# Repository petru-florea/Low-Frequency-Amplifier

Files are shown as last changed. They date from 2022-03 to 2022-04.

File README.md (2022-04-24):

# Low Frequency Amplifier
### Revision 1.0
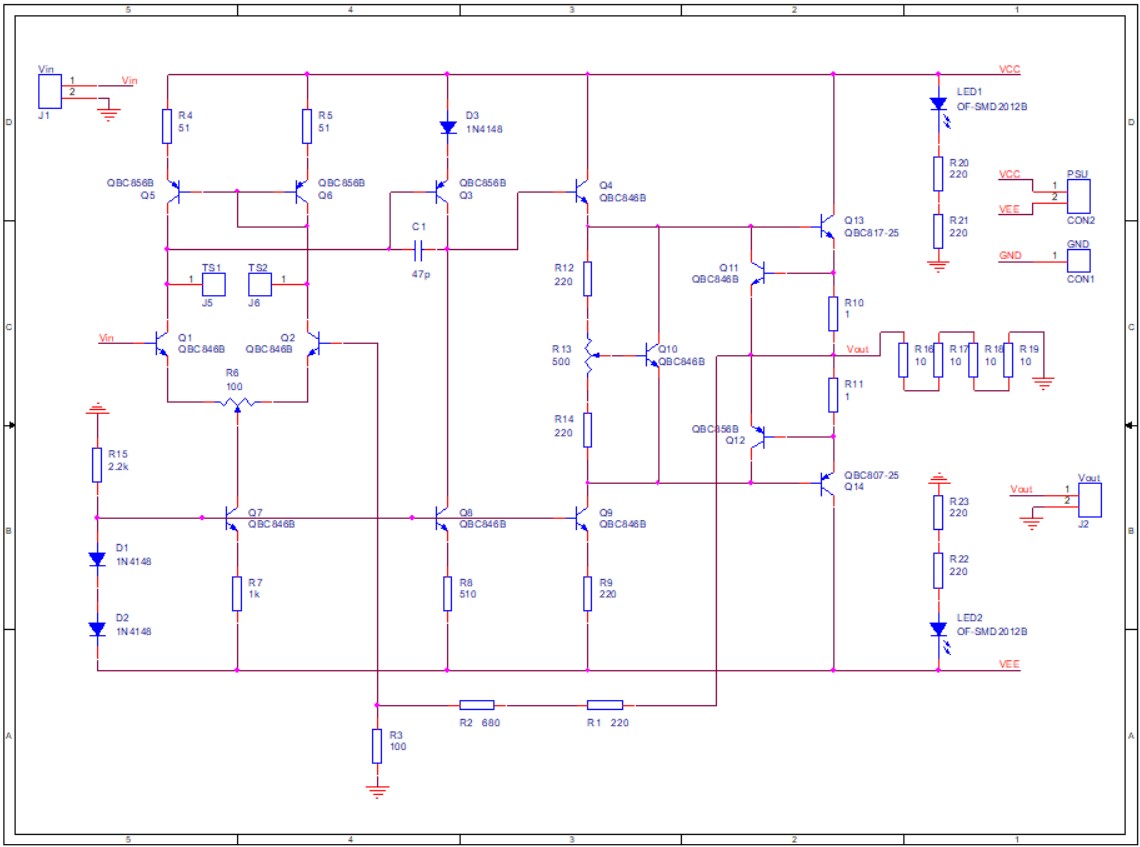
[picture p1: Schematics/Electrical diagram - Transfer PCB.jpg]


---
# README

### Quick summary

This is a BJT based Class AB low frquency amplifier (audio amplifier) PCB design using SMD technology.

This repository contains the OrCad design files, manufacturing Gerber/drill files, PDF/drawing files, and relevant documenation for this board.

### Design characteristics

+ VCC: 10V; VEE: -10V
+ Input signal, *ui* in the range: ±1 [V]
+ Output load, *RL*: 40 [Ω]
+ Input resistance *Ri* > 0.1 [MΩ]
+ Output resistance *Ro* < 0.8 [Ω]
+ Voltage gain, *Av*: 10
+ Operating temperature range: -20 - 120°C
+ The presence of supply voltages is signaled by two LEDs

### Project folder structure

Starting from the top level:
+ *Bill_of_Materials*  - This contains the bill of materials in .xls and .BOM formats
+ *Data sheets* - This contains the data sheets for the electronic devices used
+ *Layout* - This contains the PCB Gerbers and drill file for manufacture, there is also a .jpg image with the PCB layout
+ *Project docs* - This contains the relevant documenation for this project (in Romanian)
+ *Schematics* - This contains the original OrCad schematic and design files. There are two folders inside: 
    - *Simulation* - contains the OrCad schematic used for circuit simulation
    - *Transfer PCB* - contains the OrCad schematic used for exporting the circuit to the OrCad PCB Editor
+ *Simulations* - This folder contains images of different simulations that prove the circuit is working adequately

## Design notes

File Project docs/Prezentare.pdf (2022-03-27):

## UNIVERSITATEA POLITEHNICA din BUCURESTI

Facultatea de Electronică, Telecomunicații și Tehnologia Informației

### Referat

### Proiect 1 - Dispozitive și circuite electronice

### Tema:

Amplificator de tensiune (joasă frecvență)

Florea Petru
Grupa: 432E

Bucuresti 2021

Date initiale de proiectare: N = 8

Să se proiecteze și realizeze un amplificator de tensiune (joasă frecvență) având următoarele caracteristici:
- Semnal de intrare, ui in gama: 400 [mV];
- Sarcina la ieșire, RL: 40 [Ω];
- Rezistența de intrare Ri > 0,1 [MΩ];
- Rezistența de ieșire Ro < 0,8 [Ω];
- Amplificare în tensiune, Av: 10;
- Domeniul temperaturilor de funcționare: 0-70ºC (verificabil prin testare în temperatură);
- Semnalizarea prezenței tensiunilor de alimentare cu diodă de tip LED.

Introducere:
Amplificatorul de tensiune este un circuit care are rolul de a furniza la iesirea sa o tensiune proportionala cu cea de la intrare. Relatia de baza este:

Uies=AV⋅Uin (1)

unde:
- Uies= este tensiunea de la iesirea amplificatorului
- Uin= este tensiunea de la intrarea amplificatorului
- Av= amplificarea amplificatorului (marime adimensionala) mai mare, in modul decat 1. Daca Av>0, atunci amplificatorul se numeste neinversor, iar daca Av<0, amplificatorul se numeste inversor.

Formula (1) este mai greu de indeplinit cu exactitate in practica, deoarece marimea Av nu este constanta, si depinde de mai multi factori, printre care si Uin, ceea ce face ca amplificatoarele de precizie sa fie realizare cu reactie negativa puternica. Pentru aceasta, se realizeaza un amplificator cu doua intrari: una inversoare, si cealalta neinversoare (amplificator diferential). Amplificatorul amplifica de fapt diferenta tensiunilor de la intrarea neinversoare, respectiv inversoare.

La intrarea neinversoare se aplica semnalul, iar la cea inversoare o fractiune din tensiunea de la iesirea amplificatorului, f⋅Uies cu f<1.

Daca amplificarea in bucla deschisa av (calculata in lipsa reactiei negative – intrarea inversoare conectcata la masa) indeplineste relatia:
aV

⋅f >>1

se poate demonstra ca amplificarea in prezenta reactiei negative AV≅1/f, deci constanta.

Schema bloc a amplificatorului de tensiune:

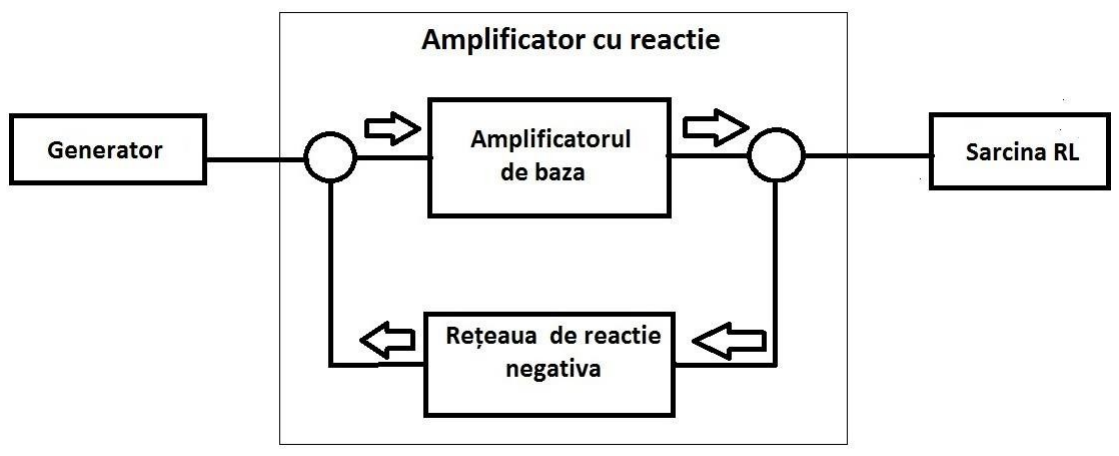
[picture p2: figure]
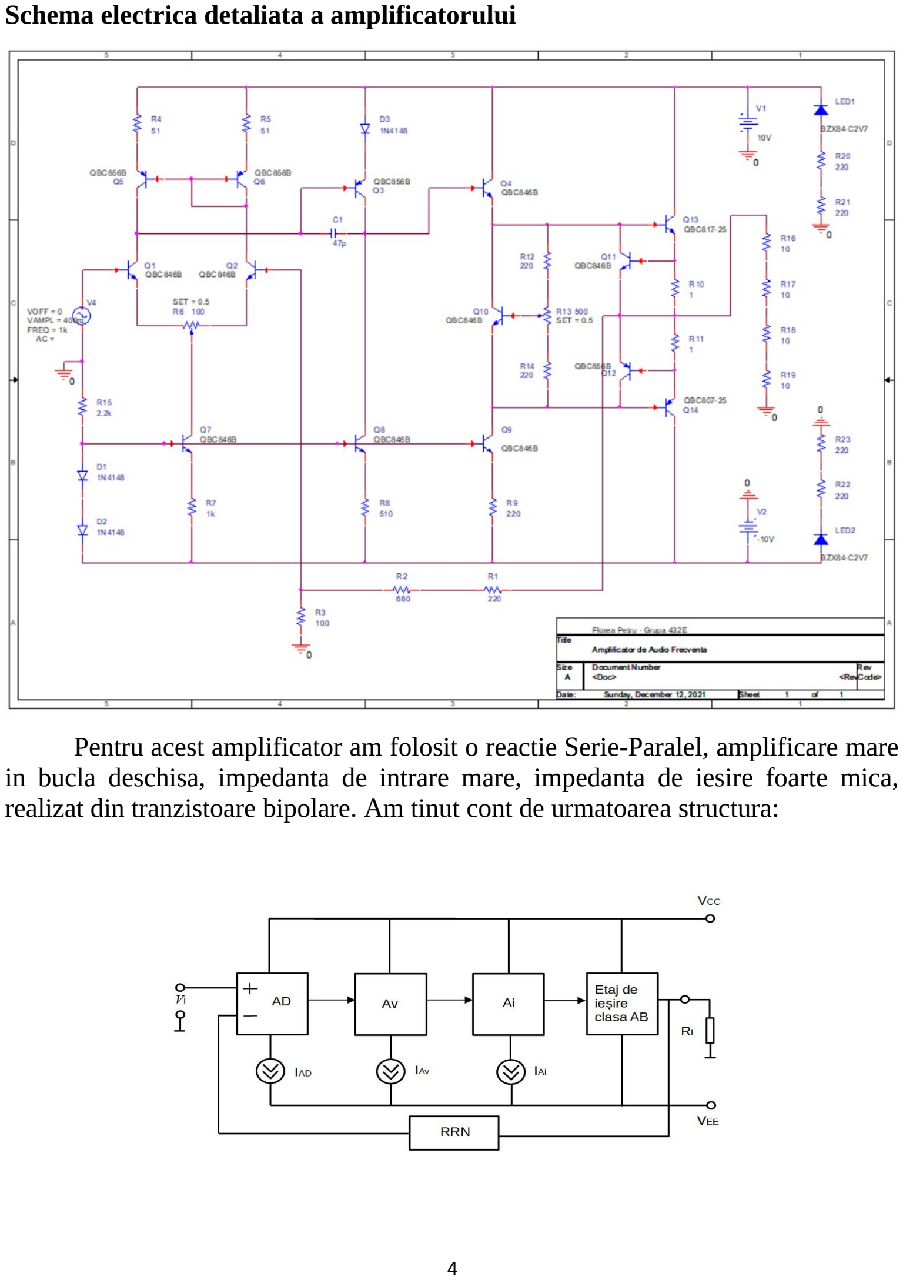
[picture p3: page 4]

Schema electrica detaliata a amplificatorului

Pentru acest amplificator am folosit o reactie Serie-Paralel, amplificare mare in bucla deschisa, impedanta de intrare mare, impedanta de iesire foarte mica, realizat din tranzistoare bipolare. Am tinut cont de urmatoarea structura:

Circuitul de intrare Q1 si Q2 este un amplificator diferential cu tranzistoare bipolare de joasa frecventa si mica putere. Curentul prin cele 2 tranzistoare este dat de sursa de curent Q7. Curentul prin acest tranzistor este dat de relatia:
I = (2VD-VBE)/R7 = 0,6 mA. Acest tranzistor alimenteaza cele 2 tranzistoare din diferential cu un curent simetric de aproximativ 0,3 mA.
Etajul diferential continua cu o oglinda de curent simetrica. Tranzistoarele Q5 si Q6 sunt tranzistoare de putere mica (65V, 100mA, β=290) ce au cate o rezistenta de 51Ω in emitor. Rolul acestei oglinzi de curent este sa forteze acelasi curent la iesirea din oglinda, pentru a avea liniaritate cat mai buna si distorsiuni cat mai mici.
Etajul diferential este urmat de amplificatorul in tensiune Q3, care este un tranzistor PNP de mica putere (65V, 100mA, β=290). Condensatorul conectat intre baza si colectorul tranzistorului Q3 este un condensator de compensare (efectul Miller), acesta are rolul de a modifica banda de frecventa. Alimentarea etajului este asigurata de tranzistorul Q8. Curentul prin acest tranzistor este dat de relatia: I = (2VD-VBE)/R8 = 1,1 mA
Etajul final este in clasa AB, fiind compus din 2 tranzistoare de putere medie Q13, Q14 (45V, 800mA, β =160). Etajul AB asigura o amplificare in putere cu un randament bun la un nivel de distorsiuni redus. De asemenea, a fost indrodusa protectia la suprasarcina sau scurtcircuit. Aceasta protectie este realizata cu grupul Q11, R10 pentru tranzistorul Q13 si grupul Q12, R11 pentru tranzistorul Q14. Diodele LED lucreaza in conductie, datorata rezistentei de 440Ω in serie. Diodele cu jonctiune p-n lucreaza in conductie: diodele D1 si D2 avand un curent de aproximativ 4 mA, iar D3 de aproximativ 1,1 mA.
Reteaua de reactie negative este alcatuita din tranzistorul Q2, respectiv rezistentele R1, R2 si R3. Amplificare in bucla inchisa a montajului este data de formula A=(R1+R2+R3)/R3. Pentru a respecta cerintele de proiectare, am ales raportul rezistentelor sa fie aproximativ 9.

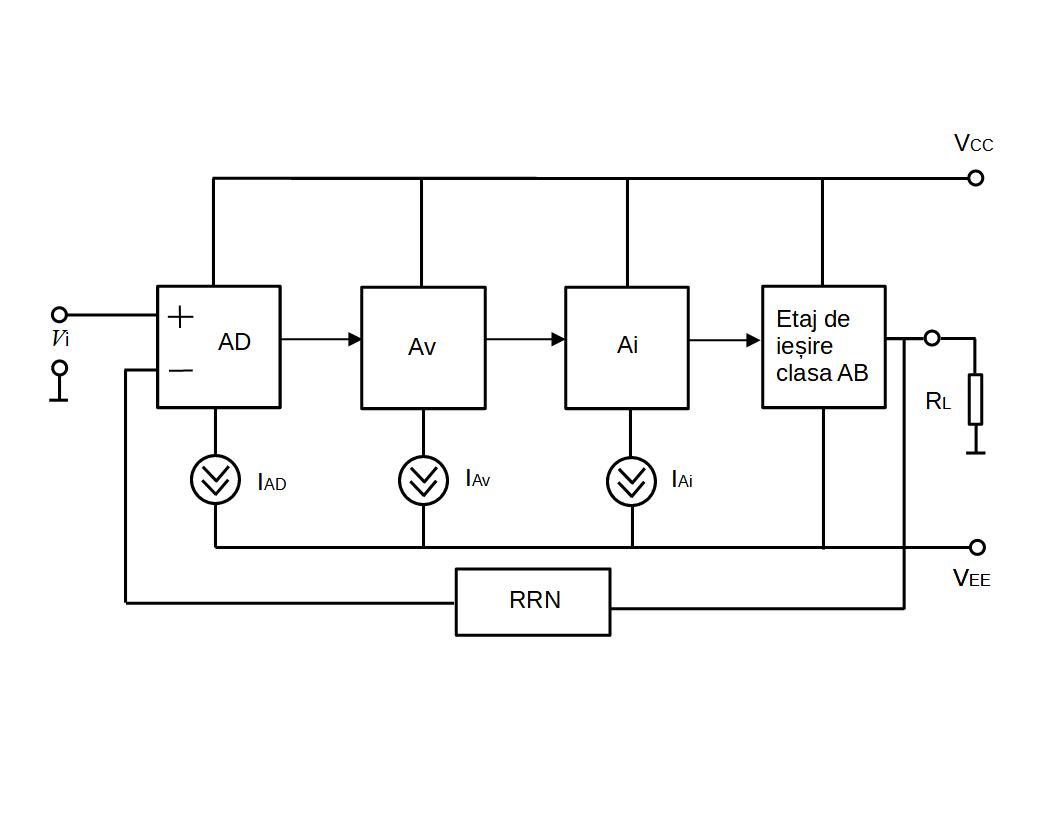
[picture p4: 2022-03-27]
Block schematic.jpg

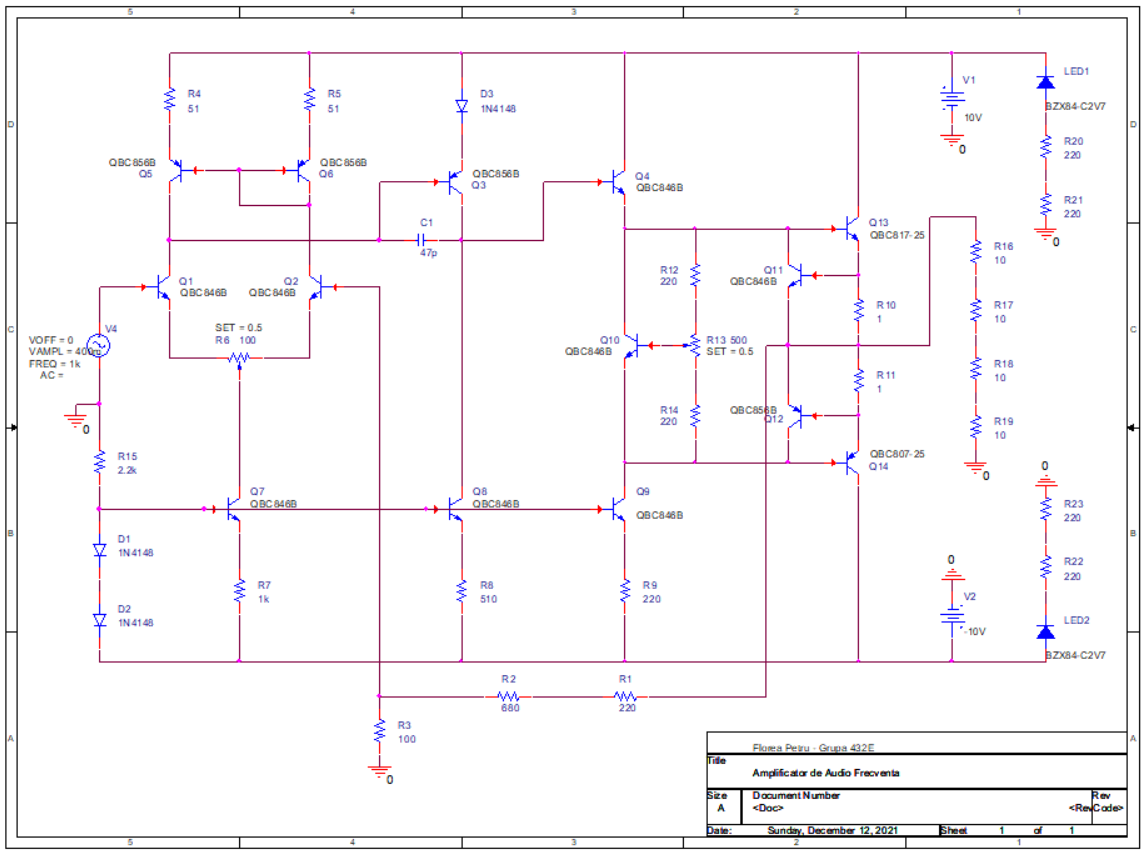
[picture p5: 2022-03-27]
Schematics/Electrical diagram - Simulation.PNG

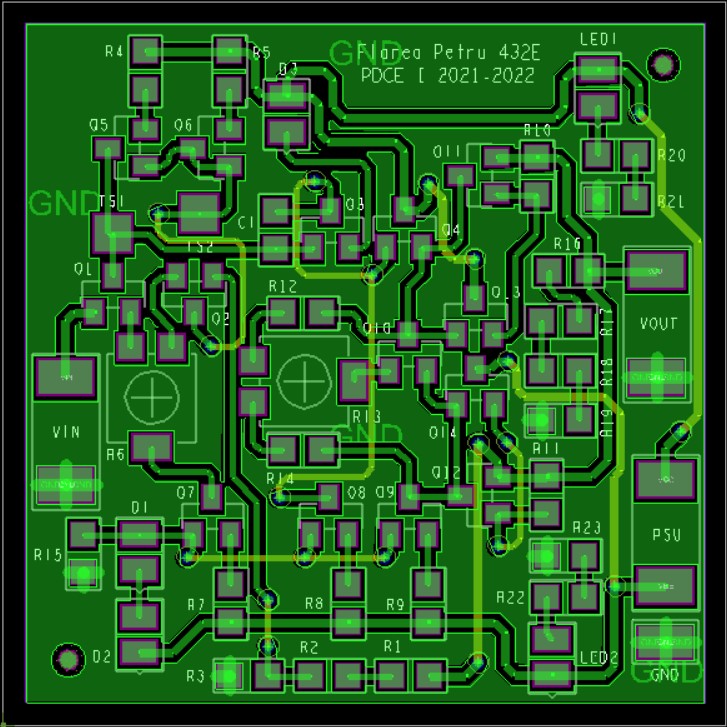
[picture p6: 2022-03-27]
Layout/Layout.jpg

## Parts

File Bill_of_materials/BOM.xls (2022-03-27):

Anexa a1 - Grupa 432E - Tema 2 - Amplificator de tensiune (joasă frecvență)
Nr. Crt. | Nume | Catalog | Cod distrib | Nume prod | Prod | Clasă | Qty fix | Qty final | Qty min | Descriere | Distribuitor | Pret (fara TVA) referinta/buc. TME România | Pret total pe reper (fara TVA) - propus
1 | 0 ohm | (LINK) (http://www.tme.eu/ro/details/smd1206-0r/rezistente-smd-1206/royal-ohm/1206s4j0000t5e/) | 1206S4J0000T5E | 1206S4J0000T5E | SR PASSIVES | rezistor | 0 |  | 0 | Rezistor: thick film; SMD; 1206; 0Ω; 0,25W; ±5%; -55÷125°C | TME România | 0.03841 | 0
2 | 0.47 | (LINK) (http://www.tme.eu/ro/details/smd0805-0r47/rezistente-smd-0805/royal-ohm/0805s8j047kt5e/) | SMD0805-0R47 | 0805S8J047KT5E | ROYAL OHM | rezistor | 30 |  | 0 | Rezistor SMD, chip, 0805, 0.47Ω, ±5%, 0.125W | TME România | 0.01454 | 0.4362
3 | 1 | (LINK) (https://www.tme.eu/ro/details/smd0805-1r/rezistente-smd-0805/royal-ohm/0805s8j010jt5e/) | SMD0805-1R-5% | 0805S8J010JT5E | ROYAL OHM | rezistor | 30 |  | 2 | Rezistor SMD, chip, 0805, 1Ω, ±5%, 0.125W | TME România | 0.01723 | 0.5169
4 | 4.7 | (LINK) (https://www.tme.eu/ro/details/smd0805-4r7/rezistente-smd-0805/royal-ohm/0805s8j047jt5e/) | SMD0805-4R7-5% | 0805S8J047JT5E | ROYAL OHM | rezistor | 10 |  | 0 | Rezistor SMD, chip, 0805, 4.7Ω, ±5%, 0.125W | TME România | 0.01723 | 0.1723
5 | 10 | (LINK) (https://www.tme.eu/ro/details/smd0805-10r/rezistente-smd-0805/royal-ohm/0805s8j0100t5e/) | SMD0805-10R-5% | 0805S8J0100T5E | ROYAL OHM | rezistor | 10 |  | 4 | Rezistor SMD, chip, 0805, 10Ω, ±5%, 0.125W | TME România | 0.01723 | 0.1723
6 | 22 | (LINK) (https://www.tme.eu/ro/details/smd0805-22r-1%25/rezistente-smd-0805/royal-ohm/0805s8f220jt5e/) | SMD0805-22R-1% | 0805S8F220JT5E | ROYAL OHM | rezistor | 20 |  | 0 | Rezistor SMD, chip, 0805, 22Ω, ±1%, 0.125W | TME România | 0.02127 | 0.4254
7 | 33 | (LINK) (https://www.tme.eu/ro/details/smd0805-33r/rezistente-smd-0805/royal-ohm/0805s8j0330t5e/) | SMD0805-33R-5% | 0805S8J0330T5E | ROYAL OHM | rezistor | 20 |  | 0 | Rezistor SMD, chip, 0805, 33Ω, ±5%, 0.125W | TME România | 0.01723 | 0.3446
8 | 51 | (LINK) (http://www.tme.eu/ro/details/rc0805jr-0751r/rezistente-smd-0805/yageo/rc0805jr-0751rl/) | SMD0805-51R-5% | 0805S8J0510T5E | ROYAL OHM | rezistor | 40 |  | 2 | Rezistor SMD, chip, 0805, 51Ω, ±5%, 0.125W | TME România | 0.0261 | 1.044
9 | 68 | (LINK) (http://www.tme.eu/ro/details/smd0805-68r-1%25/rezistente-smd-0805/royal-ohm/0805s8f680jt5e/) | SMD0805-68R-1% | 0805S8F680JT5E | ROYAL OHM | rezistor | 10 |  | 0 | Rezistor SMD, chip, 0805, 68Ω, ±1%, 0.125W | TME România | 0.04662 | 0.4662
10 | 82 | (LINK) (https://www.tme.eu/ro/details/wf08p-82r-5%25/rezistente-smd-0805/walsin/wf08p820jtl/) | SMD0805-82R-5% | WF08P820JTL | WALSIN | rezistor | 20 |  | 0 | Rezistor SMD, chip, 0805, 82Ω, ±5%, 0.125W | TME România | 0.0172 | 0.344
11 | 100 | (LINK) (https://www.tme.eu/ro/details/smd0805-100r/rezistente-smd-0805/royal-ohm/0805s8j0101t5e/) | SMD0805-100R-5% | 0805S8J0101T5E | ROYAL OHM | rezistor | 60 |  | 1 | Rezistor SMD, chip, 0805, 100Ω, ±5%, 0.125W | TME România | 0.01723 | 1.0338
12 | 150 | (LINK) (https://www.tme.eu/ro/details/smd0805-150r/rezistente-smd-0805/royal-ohm/0805s8j0151t5e/) | SMD0805-150R-5% | 0805S8F1500T5E | ROYAL OHM | rezistor | 20 |  | 0 | Rezistor SMD, chip, 0805, 150Ω, ±5%, 0.125W | TME România | 0.01723 | 0.3446
13 | 220 | (LINK) (http://www.tme.eu/ro/details/smd0805-220r-1%25/rezistente-smd-0805/royal-ohm/0805s8f2200t5e/) | SMD0805-220R-5% | 0805S8J0221T5E | ROYAL OHM | rezistor | 20 |  | 8 | Rezistor SMD, chip, 0805, 220Ω, ±5%, 0.125W | TME România | 0.02127 | 0.4254
14 | 330 | (LINK) (https://www.tme.eu/ro/details/smd0805-330r/rezistente-smd-0805/royal-ohm/0805s8j0331t5e/) | SMD0805-330R-5% | 0805S8J0331T5E | ROYAL OHM | rezistor | 20 |  | 0 | Rezistor SMD, chip, 0805, 330Ω, ±5%, 0.125W | TME România | 0.01723 | 0.3446
15 | 470 | (LINK) (https://www.tme.eu/ro/details/smd0805-470r/rezistente-smd-0805/royal-ohm/0805s8j0471t5e/) | SMD0805-470R-5% | 0805S8J0471T5E | ROYAL OHM | rezistor | 20 |  | 0 | Rezistor SMD, chip, 0805, 470Ω, ±5%, 0.125W | TME România | 0.01723 | 0.3446
16 | 510 | (LINK) (https://www.tme.eu/ro/details/smd0805-510r/rezistente-smd-0805/royal-ohm/0805s8j0511t5e/) | SMD0805-510R-5% | 0805S8J0511T5E | YAGEO | rezistor | 30 |  | 1 | Rezistor SMD, chip, 0805, 510Ω, ±5%, 0.125W | TME România | 0.01723 | 0.5169
17 | 680 | (LINK) (https://www.tme.eu/ro/details/smd0805-680r/rezistente-smd-0805/royal-ohm/0805s8j0681t5e/) | SMD0805-680R-5% | 0805S8J0681T5E | ROYAL OHM | rezistor | 30 |  | 1 | Rezistor SMD, chip, 0805, 680Ω, ±5%, 0.125W | TME România | 0.01723 | 0.5169
18 | 820 | (LINK) (https://www.tme.eu/ro/details/smd0805-820r/rezistente-smd-0805/royal-ohm/0805s8j0821t5e/) | SMD0805-820R-5% | 0805S8J0821T5E | ROYAL OHM | rezistor | 20 |  | 0 | Rezistor SMD, chip, 0805, 820Ω, ±5%, 0.125W | TME România | 0.01723 | 0.3446
19 | 910 | (LINK) (https://www.tme.eu/ro/details/rc0805jr-07910r/rezistente-smd-0805/yageo/rc0805jr-07910rl/) | SMD0805-910R-5% | RC0805JR-07910RL | YAGEO | rezistor | 20 |  | 0 | Rezistor SMD, chip, 0805, 910Ω, ±5%, 0.125W | TME România | 0.0261 | 0.522
20 | 1k | (LINK) (https://www.tme.eu/ro/details/smd0805-1k/rezistente-smd-0805/royal-ohm/0805s8j0102t5e/) | SMD0805-1K-5% | 0805S8J0102T5E | ROYAL OHM | rezistor | 100 |  | 1 | Rezistor SMD, chip, 0805, 1kΩ, ±5%, 0.125W | TME România | 0.01723 | 1.723
21 | 1.5k | (LINK) (https://www.tme.eu/ro/details/wf08p-1k5-5%25/rezistente-smd-0805/walsin/wf08p152jtl/) | SMD0805-1K5-5% | WF08P152JTL | WALSIN | rezistor | 20 |  | 0 | Rezistor SMD, chip, 0805, 1.5kΩ, ±5%, 0.125W | TME România | 0.0172 | 0.344
22 | 1.8k | (LINK) (https://www.tme.eu/ro/details/smd0805-1k8/rezistente-smd-0805/royal-ohm/0805s8j0182t5e/) | SMD0805-1K8-5% | 0805S8J0182T5E | ROYAL OHM | rezistor | 20 |  | 0 | Rezistor SMD, chip, 0805, 1.8kΩ, ±5%, 0.125W | TME România | 0.01723 | 0.3446
23 | 2k | (LINK) (https://www.tme.eu/ro/details/smd0805-2k/rezistente-smd-0805/royal-ohm/0805s8j0202t5e/) | SMD0805-2K-5% | 0805S8J0202T5E | ROYAL OHM | rezistor | 80 |  | 0 | Rezistor SMD, chip, 0805, 2kΩ, ±5%, 0.125W | TME România | 0.01723 | 1.3784
24 | 2.2k | (LINK) (https://www.tme.eu/ro/details/smd0805-2k2/rezistente-smd-0805/royal-ohm/0805s8j0222t5e/) | SMD0805-2K2-5% | 0805S8J0222T5E | ROYAL OHM | rezistor | 20 |  | 1 | Rezistor SMD, chip, 0805, 2.2kΩ, ±5%, 0.125W | TME România | 0.01723 | 0.3446
25 | 2.7k | (LINK) (https://www.tme.eu/ro/details/smd0805-2k7/rezistente-smd-0805/royal-ohm/0805s8j0272t5e/) | SMD0805-2K7-5% | 0805S8F2701T5E | ROYAL OHM | rezistor | 20 |  | 0 | Rezistor SMD, chip, 0805, 2.7kΩ, ±5%, 0.125W | TME România | 0.01723 | 0.3446
26 | 3.3k | (LINK) (https://www.tme.eu/ro/details/smd0805-3k3/rezistente-smd-0805/royal-ohm/0805s8j0332t5e/) | SMD0805-3K3-5% | 0805S8J0332T5E | ROYAL OHM | rezistor | 30 |  | 0 | Rezistor SMD, chip, 0805, 3.3kΩ, ±5%, 0.125W | TME România | 0.01723 | 0.5169
27 | 3.9k | (LINK) (https://www.tme.eu/ro/details/smd0805-3k9/rezistente-smd-0805/royal-ohm/0805s8j0392t5e/) | SMD0805-3K9-5% | 0805S8J0392T5E | ROYAL OHM | rezistor | 20 |  | 0 | Rezistor SMD, chip, 0805, 3.9kΩ, ±5%, 0.125W | TME România | 0.01723 | 0.3446
28 | 4.7k | (LINK) (https://www.tme.eu/ro/details/smd0805-4k7/rezistente-smd-0805/royal-ohm/0805s8j0472t5e/) | SMD0805-4K7-5% | 0805S8J0472T5E | ROYAL OHM | rezistor | 30 |  | 0 | Rezistor SMD, chip, 0805, 4.7kΩ, ±5%, 0.125W | TME România | 0.01723 | 0.5169
29 | 5.6k | (LINK) (https://www.tme.eu/ro/details/smd0805-5k6/rezistente-smd-0805/royal-ohm/0805s8j0562t5e/) | SMD0805-5K6-5% | 0805S8J0562T5E | ROYAL OHM | rezistor | 40 |  | 0 | Rezistor SMD, chip, 0805, 5.6kΩ, ±5%, 0.125W | TME România | 0.01723 | 0.6892
30 | 6.8k | (LINK) (https://www.tme.eu/ro/details/rc0805jr-076k8/rezistente-smd-0805/yageo/rc0805jr-076k8l/) | SMD0805-6K8-5% | RC0805JR-076K8L | YAGEO | rezistor | 20 |  | 0 | Rezistor SMD, chip, 0805, 6.8kΩ, ±5%, 0.125W | TME România | 0.0261 | 0.522
31 | 8.2k | (LINK) (https://www.tme.eu/ro/details/smd0805-8k2/rezistente-smd-0805/royal-ohm/0805s8j0822t5e/) | SMD0805-8K2-5% | 0805S8J0822T5E | ROYAL OHM | rezistor | 30 |  | 0 | Rezistor SMD, chip, 0805, 8.2kΩ, ±5%, 0.125W | TME România | 0.01723 | 0.5169
32 | 9.1k | (LINK) (https://www.tme.eu/ro/details/smd0805-9k1/rezistente-smd-0805/royal-ohm/0805s8j0912t5e/) | SMD0805-9K1-5% | 0805S8J0912T5E | ROYAL OHM | rezistor | 20 |  | 0 | Rezistor SMD, chip, 0805, 9.1kΩ, ±5%, 0.125W | TME România | 0.01723 | 0.3446
33 | 10k | (LINK) (https://www.tme.eu/ro/details/smd0805-10k/rezistente-smd-0805/royal-ohm/0805s8j0103t5e/) | SMD0805-10K-5% | 0805S8J0103T5E | ROYAL OHM | rezistor | 100 |  | 0 | Rezistor SMD, chip, 0805, 10kΩ, ±5%, 0.125W | TME România | 0.01723 | 1.723
34 | 15k | (LINK) (https://www.tme.eu/ro/details/smd0805-15k/rezistente-smd-0805/royal-ohm/0805s8j0153t5e/) | SMD0805-15K-5% | 0805S8J0153T5E | ROYAL OHM | rezistor | 30 |  | 0 | Rezistor SMD, chip, 0805, 15kΩ, ±5%, 0.125W | TME România | 0.01723 | 0.5169
35 | 22k | (LINK) (https://www.tme.eu/ro/details/smd0805-22k/rezistente-smd-0805/royal-ohm/0805s8j0223t5e/) | SMD0805-22K-5% | 0805S8J0223T5E | ROYAL OHM | rezistor | 30 |  | 0 | Rezistor SMD, chip, 0805, 22kΩ, ±5%, 0.125W | TME România | 0.01723 | 0.5169
36 | 47k | (LINK) (http://www.tme.eu/ro/details/smd0805-47k/rezistente-smd-0805/royal-ohm/0805s8j0473t5e/) | SMD0805-47K-5% | 0805S8J0473T5E | ROYAL OHM | rezistor | 40 |  | 0 | Rezistor: thick film; SMD; 0805; 47kΩ; 0,125W; ±5%; -55÷125°C | TME România | 0.01723 | 0.6892
37 | 68k | (LINK) (https://www.tme.eu/ro/details/smd0805-68k/rezistente-smd-0805/royal-ohm/0805s8j0683t5e/) | SMD0805-68K-5% | 0805S8J0683T5E | ROYAL OHM | rezistor | 20 |  | 0 | Rezistor SMD, chip, 0805, 68kΩ, ±5%, 0.125W | TME România | 0.01723 | 0.3446
38 | 100k | (LINK) (https://www.tme.eu/ro/details/smd0805-100k/rezistente-smd-0805/royal-ohm/0805s8j0104t5e/) | SMD0805-100K-5% | 0805S8J0104T5E | ROYAL OHM | rezistor | 100 |  | 0 | Rezistor SMD, chip, 0805, 100kΩ, ±5%, 0.125W | TME România | 0.01723 | 1.723
39 | 150k | (LINK) (http://www.tme.eu/ro/details/smd0805-150k/rezistente-smd-0805/royal-ohm/0805s8j0154t5e/) | SMD0805-150K-5% | 0805S8J0154T5E | ROYAL OHM | rezistor | 30 |  | 0 | Rezistor SMD, chip, 0805, 150kΩ, ±5%, 0.125W | TME România | 0.01723 | 0.5169
40 | 180k | (LINK) (http://www.tme.eu/ro/details/smd0805-180k/rezistente-smd-0805/royal-ohm/0805s8j0184t5e/) | SMD0805-180K-5% | 0805S8J0184T5E | ROYAL OHM | rezistor | 30 |  | 0 | Rezistor SMD, chip, 0805, 180kΩ, ±5%, 0.125W | TME România | 0.01723 | 0.5169
41 | 220k | (LINK) (https://www.tme.eu/ro/details/smd0805-220k/rezistente-smd-0805/royal-ohm/0805s8j0224t5e/) | SMD0805-220K-5% | 0805S8J0224T5E | ROYAL OHM | rezistor | 30 |  | 0 | Rezistor SMD, chip, 0805, 220kΩ, ±5%, 0.125W | TME România | 0.01723 | 0.5169
42 | 330k | (LINK) (https://www.tme.eu/ro/details/smd0805-330k/rezistente-smd-0805/royal-ohm/0805s8j0334t5e/) | SMD0805-330K-5% | 0805S8J0334T5E | ROYAL OHM | rezistor | 30 |  | 0 | Rezistor SMD, chip, 0805, 330kΩ, ±5%, 0.125W | TME România | 0.01723 | 0.5169
43 | 390k | (LINK) (https://www.tme.eu/ro/details/smd0805-390k/rezistente-smd-0805/royal-ohm/0805s8j0394t5e/) | SMD0805-390K-5% | 0805S8J0394T5E | ROYAL OHM | rezistor | 30 |  | 0 | Rezistor SMD, chip, 0805, 390kΩ, ±5%, 0.125W | TME România | 0.01723 | 0.5169
44 | 510k | (LINK) (https://www.tme.eu/ro/details/smd0805-510k/rezistente-smd-0805/royal-ohm/0805s8j0514t5e/) | SMD0805-510K-5% | 0805S8J0514T5E | ROYAL OHM | rezistor | 30 |  | 0 | Rezistor SMD, chip, 0805, 510kΩ, ±5%, 0.125W | TME România | 0.01723 | 0.5169
45 | 1M | (LINK) (https://www.tme.eu/ro/details/crcw08051m00jntabc/rezistente-smd-0805/vishay/) | SMD0805-1M-5% | CRCW08051M00JNTABC | VISHAY | rezistor | 30 |  | 0 | Rezistor SMD, chip, 0805, 1MΩ, ±5%, 0.125W | TME România | 0.01151 | 0.3453
46 | 2M | (LINK) (http://www.tme.eu/ro/details/smd0805-2m/rezistente-smd-0805/royal-ohm/0805waj-2m-t5e/) | SMD0805-2M7 5% | 0805WAJ 2M T5E | ROYAL OHM | rezistor | 30 |  | 0 | Rezistor SMD, chip, 0805, 2MΩ, ±1%, 0.125W | TME România | 0.01723 | 0.5169
47 | 5,1M | (LINK) (http://www.tme.eu/ro/details/smd0805-5m1/rezistente-smd-0805/royal-ohm/0805s8j0515t5e/) | SMD0805-5M1 5% | RC0805FR-075M1 | Yageo | rezistor | 30 |  | 0 | Rezistor SMD, chip, 0805, 5.1MΩ, ±1%, 0.125W | TME România | 0.01723 | 0.5169
48 | 10M | (LINK) (https://www.tme.eu/ro/details/0805s8j0106t5e/rezistente-smd-0805/royal-ohm/) | SMD0805-10M 5% | 0805S8J0106T5E | ROYAL OHM | rezistor | 20 |  | 0 | Rezistor SMD, chip, 0805, 10MΩ, ±5%, 0.125W | TME România | 0.01723 | 0.3446
49 | 100ohm | (LINK) (https://www.tme.eu/ro/details/ts53yl100r/trimere-smd-cu-o-singura-tura/vishay/ts53yl101mr10/) | 1804GSMD-100R | 1804GSMD-100R | SR PASSIVES | potențiometru | 20 |  | 1 | Potențiome-tru liniar, simplă tură, SMD, 100Ω, ±10%, 100ppm/°C, 0.25W | TME România | 3.77 | 75.4
50 | 500ohm | (LINK) (https://www.tme.eu/ro/details/ts53yl500r/trimere-smd-cu-o-singura-tura/vishay/ts53yl501mr10/) | 1804GSMD-500R | 1804GSMD-500R | VISHAY | potențiometru | 10 |  | 1 | Potențiome-tru liniar, simplă tură, SMD, 500Ω, ±10%, 100ppm/°C, 0.25W | TME România | 2.19 | 21.9
51 | 2k | (LINK) (https://www.tme.eu/ro/details/ts53yl2k/trimere-smd-cu-o-singura-tura/vishay/ts53yl202mr10/) | TS53YL202MR10 | TS53YL202MR10 | VISHAY | potențiometru | 50 |  | 0 | Potențiome-tru liniar, simplă tură, SMD, 2kΩ, ±20%, 100ppm/°C, 0.25W | TME România | 2.84 | 142
52 | 5k | (LINK) (http://www.tme.eu/ro/details/3314g-1-502e/trimere-smd-cu-o-singura-tura/bourns/) | 3314G-1-502E | 3314G-1-502E | BOURNS | potențiometru | 0 |  | 0 | Potențiome-tru liniar, simplă tură, SMD, 5kΩ, ±20%, 100ppm/°C, 0.25W | TME România | 3.45 | 0
53 | 10k | (LINK) (http://www.tme.eu/ro/details/3314g-1-103e/trimere-smd-cu-o-singura-tura/bourns/) | 3314G-1-103E | 3314G-1-103E | BOURNS | potențiometru | 0 |  | 0 | Potențiome-tru liniar, simplă tură, SMD, 10kΩ, ±20%, 100ppm/°C, 0.25W | TME România | 3.0573 | 0
54 | 50k | (LINK) (http://www.tme.eu/ro/details/3314g-1-503e/trimere-smd-cu-o-singura-tura/bourns/) | 3314G-1-503E | 3314G-1-503E | BOURNS | potențiometru | 0 |  | 0 | Potențiome-tru liniar, simplă tură, SMD, 50kΩ, ±20%, 100ppm/°C, 0.25W | TME România | 2.84 | 0
55 | 100k | (LINK) (http://www.tme.eu/ro/details/ts53yl100k/trimere-smd-cu-o-singura-tura/vishay/ts53yl104mr10/) | TS53YL104MR10 | TS53YL104MR10 | VISHAY | potențiometru | 0 |  | 0 | Potențiome-tru liniar, simplă tură, SMD, 100kΩ, ±20%, 100ppm/°C, 0.25W | TME România | 2.61 | 0
56 | 500k | (LINK) (http://www.tme.eu/ro/details/3314g-1-504e/trimere-smd-cu-o-singura-tura/bourns/) | 3314G-1-504E | 3314G-1-504E | BOURNS | potențiometru | 0 |  | 0 | Potențiome-tru liniar, simplă tură, SMD, 500kΩ, ±10%, 100ppm/°C, 0.25W | TME România | 2.8802 | 0
 | TOTAL - Componente pasive (rezistoare de valori fixe şi reglabile) |  |  |  |  |  |  |  |  | FARA TVA = | 265.8843 | CU TVA= | 329.696532
57 | 4.7pF | (LINK) (http://www.tme.eu/ro/details/cc0805crnpo94r7/condensatoare-mlcc-smd-0805/yageo/cc0805crnpo9bn4r7/) | CC0805CRNPO9BN4R7 | CC0805CRNPO9BN4R7 | YAGEO | condensator | 20 |  | 0 | ceramic; MLCC; 4,7pF; 50V; C0G; ±0,25pF; SMD; 0805 | TME România | 0.16643 | 3.3286
58 | 10pF | (LINK) (http://www.tme.eu/ro/details/cc0805jrnpo9100/condensatoare-mlcc-smd-0805/yageo/cc0805jrnpo9bn100/) | CC0805JRNPO9BN100 | CC0805JRNPO9BN100 | YAGEO | condensator | 20 |  | 0 | ceramic; MLCC; 10pF; 50V; C0G; ±5%; SMD; 0805 | TME România | 0.1649 | 3.298
59 | 47pF | (LINK) (http://www.tme.eu/ro/details/cl21c470jbannnc/condensatoare-mlcc-smd-0805/samsung/) | CL21C470JBANNNC | CL21C470JBANNNC | SAMSUNG | condensator | 20 |  | 1 | Condensator: ceramic; MLCC; 47pF; 50V; C0G; ±5%; SMD; 0805; -55÷125°C | TME România | 0.11097 | 2.2194
60 | 100pF | (LINK) (http://www.tme.eu/ro/details/cl21c101jbannnc/condensatoare-mlcc-smd-0805/samsung/) | CL21C101JBANNNC | CL21C101JBANNNC | SAMSUNG | condensator | 20 |  | 0 | Condensator: ceramic; MLCC; 100pF; 50V; C0G; ±5%; SMD; 0805 | TME România | 0.05427 | 1.0854
61 | 470pF | (LINK) (https://www.tme.eu/ro/details/cl21c471jbannnc/condensatoare-mlcc-smd-0805/samsung/) | CL21C471JBANNNC | CL21C471JBANNNC | SAMSUNG | condensator | 20 |  | 0 | Condensator: ceramic; MLCC; 470pF; 50V; X7R; ±10%; SMD; 0805 | TME România | 0.12123 | 2.4246
62 | 1nF | (LINK) (https://www.tme.eu/ro/details/cl21c102jbcnnnc/condensatoare-mlcc-smd-0805/samsung/) | CL21C102JBCNNNC | CL21C102JBCNNNC | SAMSUNG | condensator | 40 |  | 0 | Condensator MLCC, SMD, 0805, 1nF, ±5%, 50V, C0G | TME România | 0.06487 | 2.5948
63 | 2.2nF | (LINK) (https://www.tme.eu/ro/details/cl21b222jbannnc/condensatoare-mlcc-smd-0805/samsung/) | CL21B222JBANNNC | CL21B222JBANNNC | SAMSUNG | condensator | 0 |  | 0 | Condensator: ceramic; MLCC; 2,2nF; 50V; X7R; ±10%; SMD; 0805 | TME România | 0.1485 | 0
64 | 4.7nF | (LINK) (https://www.tme.eu/ro/details/cl21b472kbannnc/condensatoare-mlcc-smd-0805/samsung/) | CL21B472KBANNNC | CL21B472KBANNNC | SAMSUNG | condensator | 0 |  | 0 | Condensator MLCC, SMD, 0805, 4.7nF, ±5%, 50V, X7R | TME România | 0.08943 | 0
65 | 5.6nF | (LINK) (https://www.tme.eu/ro/details/cl21b562kbannnc/condensatoare-mlcc-smd-0805/samsung/) | CL21B562KBANNNC | CL21B562KBANNNC | SAMSUNG | condensator | 0 |  | 0 | Condensator MLCC, SMD, 0805, 5.6nF, ±5%, 50V, X7R | TME România | 0.04517 | 0
66 | 10nF | (LINK) (https://www.tme.eu/ro/details/cl21b103kbannnd/condensatoare-mlcc-smd-0805/samsung/) | CL21B103KBANNND | CL21B103KBANNND | SAMSUNG | condensator | 0 |  | 0 | Condensator MLCC, SMD, 0805, 10nF, ±5%, 50V, X7R | TME România | 0.06093 | 0
67 | 22nF | (LINK) (http://www.tme.eu/ro/details/cl21b223kcfnnne/condensatoare-mlcc-smd-0805/samsung/) | CL21B223KBANNNC | CL21B223KBANNNC | SAMSUNG | condensator | 0 |  | 0 | Condensator: ceramic; MLCC; 22nF; 100V; X7R; ±10%; SMD; 0805 | TME România | 0.13823 | 0
68 | 33nF | (LINK) (https://www.tme.eu/ro/details/vj0805y333kxacw1bc/condensatoare-mlcc-smd-0805/vishay/) | VJ0805Y333KXACW1BC | VJ0805Y333KXACW1BC | VISHAY | condensator | 0 |  | 0 | Condensator: ceramic; MLCC; 33nF; 50V; X7R; ±10%; SMD; 0805 | TME România | 0.05417 | 0
69 | 100nF | (LINK) (https://www.tme.eu/ro/details/cl21f104zbcnnnc/condensatoare-mlcc-smd-0805/samsung/) | CL21F104ZBCNNNC | CL21F104ZBCNNNC | SAMSUNG | condensator | 40 |  | 0 | ceramic; MLCC; 100nF; 50V; X7R; ±10%; SMD; 0805 | TME România | 0.3759 | 15.036
70 | 220nF | (LINK) (http://www.tme.eu/ro/details/cl21b224kafnnne/condensatoare-mlcc-smd-0805/samsung/) | CL21B224KAFNNNE | CL21B224KAFNNNE | SAMSUNG | condensator | 0 |  | 0 | Condensator: ceramic; MLCC; 220nF; 25V; X7R; ±10%; SMD; 0805 | TME România | 0.10247 | 0
71 | 330nF | (LINK) (https://www.tme.eu/ro/details/grm219r71h334ka88d/condensatoare-mlcc-smd-0805/murata/) | GRM219R71H334KA88D | GRM219R71H334KA88D | MURATA | condensator | 0 |  | 0 | Condensator: ceramic; MLCC; 330nF; 50V; X7R; ±10%; SMD; 0805 | TME România | 0.5972 | 0
72 | 470nF | (LINK) (https://www.tme.eu/ro/details/cc0805mry5v8474/condensatoare-mlcc-smd-0805/yageo/cc0805mry5v8bb474/) | CC0805MRY5V8474 | CC0805MRY5V8BB474 | YAGEO | condensator | 0 |  | 0 | Condensator: ceramic; MLCC; 470nF; 50V; Y5V; -20÷+80%; SMD; 0805 | TME România | 0.0758 | 0
73 | 1uF | (LINK) (https://www.tme.eu/ro/details/cl21b105kbfnnng/condensatoare-mlcc-smd-0805/samsung/) | CL21B105KBFNNNG | CL21B105KBFNNNG | SAMSUNG | condensator | 20 |  | 0 | Condensator: ceramic; MLCC; 1uF; 50V; X7R; ±20%; SMD; 0805 | TME România | 0.25253 | 5.0506
74 | 2.2uF | (LINK) (https://www.tme.eu/ro/details/grm21br61h225ka73l/condensatoare-mlcc-smd-0805/murata/) | GRM21BR61H225KA73L | GRM21BR61H225KA73L | MURATA | condensator | 20 |  | 0 | Condensator: ceramic; MLCC; 2,2uF; 25V; X5R; ±10%; SMD; 0805 | TME România | 0.4486 | 8.972
75 | 4.7uF | (LINK) (https://www.tme.eu/ro/details/cl21a475kaqnnng/condensatoare-mlcc-smd-0805/samsung/) | CL21A475KAQNNNG | CL21A475KAQNNNG | SAMSUNG | condensator | 20 |  | 0 | ceramic; MLCC; 4,7uF; 25V; X5R; ±10%; SMD; 0805 | TME România | 0.25373 | 5.0746
76 | 10uF | (LINK) (https://www.tme.eu/ro/details/ce10_50-smd/condensatoare-electrolitice-smd-85c/) | CE10/50-SMD | CE10/50-SMD | TME | condensator | 16 |  | 0 | Condensator: electrolitic; SMD; 10uF; 50V | TME România | 0.2284 | 3.6544
 | TOTAL - Componente pasive (condensatoare) |  |  |  |  |  |  |  |  | FARA TVA = | 52.7384 | CU TVA= | 65.395616
77 | 4148 | (LINK) (http://www.tme.eu/ro/details/1n4148-0805/diode-universale-smd/dc-components/cd4148ws0805c/) | 1N4148-0805 | CD4148WS(0805C) | DC Components | diodă pn | 40 |  | 3 | Diodă comutație, SMD, 0805, 300mA, 100V | TME România | 0.04555 | 1.822
78 | LED | (LINK) (https://www.tme.eu/ro/details/of-smd2012b/diode-led-smd-colorate/optoflash/) | OF-SMD2012B | OF-SMD2012B | OPTOFLASH | LED | 15 |  | 2 | LED albastru, SMD, 0805, 150-200mcd, 476nm, 120° | TME România | 0.1264 | 1.896
79 | 2.7V | (LINK) (http://www.tme.eu/ro/details/bzx84c2v7/diode-zener-smd/on-semiconductor/bzx84c2v7lt1g/) | BZX84C2V7 | BZX84-C2V7LT1G | ON Semiconductor | diodă Zener | 0 |  | 0 | Diodă Zener, SMD, SOT23, 2,7V, ±5%, 0.25W | TME România | 0.05732 | 0
80 | 5.1V | (LINK) (https://www.tme.eu/ro/details/bzx84-c5v1.215/diode-zener-smd/nexperia/) | BZX84C5V1 | BZX84-C5V1 | NEXPERIA | diodă Zener | 10 |  | 0 | Diodă Zener, SMD, SOT23, 5,1V, ±5%, 0.3W | TME România | 0.06245 | 0.6245
81 | 5.6V | (LINK) (https://www.tme.eu/ro/details/bzx84b5v6-dio/diode-zener-smd/diotec-semiconductor/bzx84b5v6/) | BZX84B5V6 | BZX84B5V6 | DIOTEC SEMICONDUCTOR | diodă Zener | 10 |  | 0 | Diodă Zener, SMD, SOT23, 5,6V, ±5%, 0.3W | TME România | 0.0839 | 0.839
82 | 6.2V | (LINK) (https://www.tme.eu/ro/details/bzx84-c6v2.215/diode-zener-smd/nexperia/) | BZX84C6V2 | BZX84-C6V2 | NEXPERIA | diodă Zener | 0 |  | 0 | Diodă Zener, SMD, SOT23, 6.2V, ±5%, 0.3W | TME România | 0.06618 | 0
83 | 6.8V | (LINK) (https://www.tme.eu/ro/details/bzx84-c6v8.215/diode-zener-smd/nexperia/) | BZX84C6V8 | BZX84-C6V8 | NEXPERIA | diodă Zener | 0 |  | 0 | Diodă Zener, SMD, SOT23, 6.8V, ±5%, 0.3W | TME România | 0.05686 | 0
84 | 8.2V | (LINK) (https://www.tme.eu/ro/details/bzx84-c8v2.215/diode-zener-smd/nexperia/) | BZX84C8V2 | BZX84-C8V2 | NEXPERIA | diodă Zener | 0 |  | 0 | Diodă Zener, SMD, SOT23, 8.2V, ±5%, 0.3W | TME România | 0.05686 | 0
85 | 10V | (LINK) (https://www.tme.eu/ro/details/bzx84-c10.215/diode-zener-smd/nexperia/) | BZX84C10 | BZX84-C10 | NEXPERIA | diodă Zener | 0 |  | 0 | Diodă Zener, SMD, SOT23, 10V, ±5%, 0.3W | TME România | 0.05686 | 0
86 | PNP | (LINK) (http://www.tme.eu/ro/details/bc856b-dio/tranzistori-smd-pnp/diotec-semiconductor/bc856b/) | BC856B | BC856B | DIOTEC | tranzistor bipolar | 120 |  | 4 | Tranzistor bipolar PNP, SMD, SOT23, 80V, 100mA | TME România | 0.04055 | 4.866
87 | NPN | (LINK) (https://www.tme.eu/ro/details/bc846b-dio/tranzistori-smd-npn/diotec-semiconductor/bc846b/) | BC846B | BC846B | DIOTEC | tranzistor bipolar | 120 |  | 8 | Tranzistor bipolar NPN, SMD, SOT23, 65V, 100mA | TME România | 0.03379 | 4.0548
89 | N-JFET | (LINK) (http://www.tme.eu/ro/details/mmbfj309lt1g/tranzistori-canal-n-smd/on-semiconductor/) | MMBFJ309LT1G | MMBFJ309LT1G | ON Semiconductor | tranzistor NJFET | 40 |  | 0 | Tranzistor N-JFET, SMD, SOT23, 25V, 30mA | TME România | 0.8063 | 32.252
90 | P-JFET | (LINK) (http://www.tme.eu/ro/details/mmbfj177lt1g/tranzistori-canal-p-smd/on-semiconductor/) | MMBFJ177LT1G | MMBFJ177LT1G | ON Semiconductor | tranzistor PJFET | 0 |  | 0 | Tranzistor P-JFET, SMD, SOT23, 30V, 20mA | TME România | 0.8808 | 0
91 | NPN | (LINK) (http://www.tme.eu/ro/details/bc817-25-dio/tranzistori-smd-npn/diotec-semiconductor/bc817-25/) | BC817-25-DIO | BC817-25-DIO | NXP | tranzistor bipolar | 20 |  | 1 | Tranzistor bipolar NPN, SMD, SOT23, 45V, 800mA | TME România | 0.0494 | 0.988
93 | PNP | (LINK) (http://www.tme.eu/ro/details/bc807-25-dio/tranzistori-smd-pnp/diotec-semiconductor/bc807-25/) | BC807-25-DIO | BC807-25-DIO | NXP | tranzistor bipolar | 20 |  | 1 | Tranzistor bipolar PNP, SMD, SOT23, 45V, 800mA | TME România | 0.05406 | 1.0812
94 | NPN | (LINK) (http://www.tme.eu/ro/details/mjd31cg/tranzistori-smd-npn/on-semiconductor/) | MJD31CG | MJD31CG | ON Semiconductor | tranzistor bipolar | 0 |  | 0 | Tranzistor bipolar NPN, SMD, DPACK, 100V, 3A, 15W | TME România | 0.7037 | 0
96 | PNP | (LINK) (http://www.tme.eu/ro/details/mjd32cg/tranzistori-smd-pnp/on-semiconductor/) | MJD32CG | MJD32CG | ON Semiconductor | tranzistor bipolar | 0 |  | 0 | Tranzistor bipolar PNP, SMD, DPACK, 100V, 3A, 15W | TME România | 0.783 | 0
97 | Nmos | (LINK) (http://www.tme.eu/ro/details/irfr120npbf/tranzistori-canal-n-smd/international-rectifier/) | IRFR120NPBF | IRFR120NPBF | International Rectifier | tranzistor NMOS | 0 |  | 0 | Tranzistor N-MOSFET, SMD, DPAK, 100V, 9.1A, 20V, 39W | TME România | 1.03 | 0
 | TOTAL - Componente semiconductoare (tranzistoare bipolare şi cu efect de câmp, diode, LED, etc.) |  |  |  |  |  |  |  |  | FARA TVA = | 75.7235 | CU TVA= | 93.89714
98 | Conn2p | (LINK) (http://www.tme.eu/ro/details/zl301-40p/pini-cu-benzi-si-soclu/ninigi/) | ZL301-40P | ZL301-40P | NINIGI | Sir pini, pas 2,54mm, SMD | 0 |  | 0 | Sir pini, pas 2,54mm, SMD, tip tata, bareta de 40 pini | TME România | 2.3027 | 0
99 | FUSE | (LINK) (http://www.tme.eu/ro/details/3413.0116.11/sigurante-smd-1206-ultrarapide/schurter/) | 3413.0116.11 | 3413.0116.11 | SCHURTER | sigu-ranță | 0 |  | 0 | Siguranță sticlă, SMD, 1206, 1.25A, 48mΩ | TME România | 0 | 0
 | Total - Conectică, sigurante fuzibile, etc. |  |  |  |  |  |  |  |  | FARA TVA = | 0 | CU TVA= | 0
 | Total general |  |  |  |  |  |  |  |  | FARA TVA = | 394.3462 | CU TVA= | 469.271978

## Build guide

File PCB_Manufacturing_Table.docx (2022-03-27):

General info document for PCB manufacturing
No. | Item Name | File Name | | | | | | Info / Remarks / Notes
| BOARD
1 | Board Name / Number | Florea Petru 432E 2021-2022 | | | | | | -
2 | Revision Date | - | | | | | | -
3 | Board Size | 40 x 40 mm² | | | | | | -
4 | Board Quantity | 1 | | | | | | -
5 | Material / Dielectric Type | FR-4 | | | | | | -
6 | Board Thickness | 1.5 mm | | | | | | -
7 | Copper Thickness | 18 μm | | | | | | -
| LAYERS
8 | Number of Electrical Layers | 2 | | | | | | -
9 | Copper Layer TOP | TOP.art | | | | | | -
10 | Copper Layer BOTTOM | BOTTOM.art | | | | | | -
11 | Copper GND Plane | - | | | | | | -
12 | Copper PWR Plane | - | | | | | | -
13 | Copper INNER 1 | - | | | | | | -
14 | Copper INNER 2 | - | | | | | | -
15 | Solder Mask TOP | SMTOP.art | | | | | | -
16 | Solder Mask BOTTOM | SMBOT.art | | | | | | -
17 | Solder Paste TOP | SPTOP.art | | | | | | -
18 | Solder Paste BOTTOM | - | | | | | | -
19 | Peelable Mask TOP | - | | | | | | -
20 | Peelable Mask BOTTOM | - | | | | | | -
21 | Silk Screen TOP | SSTOP.art | | | | | | -
22 | Silk Screen BOTTOM | - | | | | | | -
23 | Board Outline | BO.art | | | | | | -
24 | Fabrication Drawing | FAB.art | | | | | | -
| MILLING & DRILLING
25 | Mill Drawing | - | | | | | | -
26 | Drill Drawing | - | | | | | | -
27 | N.C. Drill (for both PH & NPH) | - | | | | | | -
28 | N.C. Drill / Plated Holes (PH) | DRILL.drl | | | | | | -
29 | N.C. Drill / Non-Plated Holes (PH) | - | | | | | | -
| FINISHING
30 | Panelisation | - | | | | | | -
31 | Electrical Test | - | | | | | | -
32 | Copper Finishing | x | HASL | | OSP | | | ENIG
33 | Board Outline Machining | | Routing | | Milling | | x | V-Cutting
34 | Final remarks | - | | | | -
